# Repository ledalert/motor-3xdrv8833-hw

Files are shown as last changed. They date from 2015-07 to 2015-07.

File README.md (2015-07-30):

# motor-3xdrv8833-hw
Small stepper/dc motor driver board with 3 drv8833

This is still early prototype development. Will add more information once this prototype have been tested.

### Update 2015-07-30
#### Prototype boards have arrived
Silk width was a bit too thin and testing of the boards will be done in the near future.
<a href="http://imgur.com/2IHrIkU">source: imgur.com</a>

### Update 2015-07-20
####Prototype boards have been ordered

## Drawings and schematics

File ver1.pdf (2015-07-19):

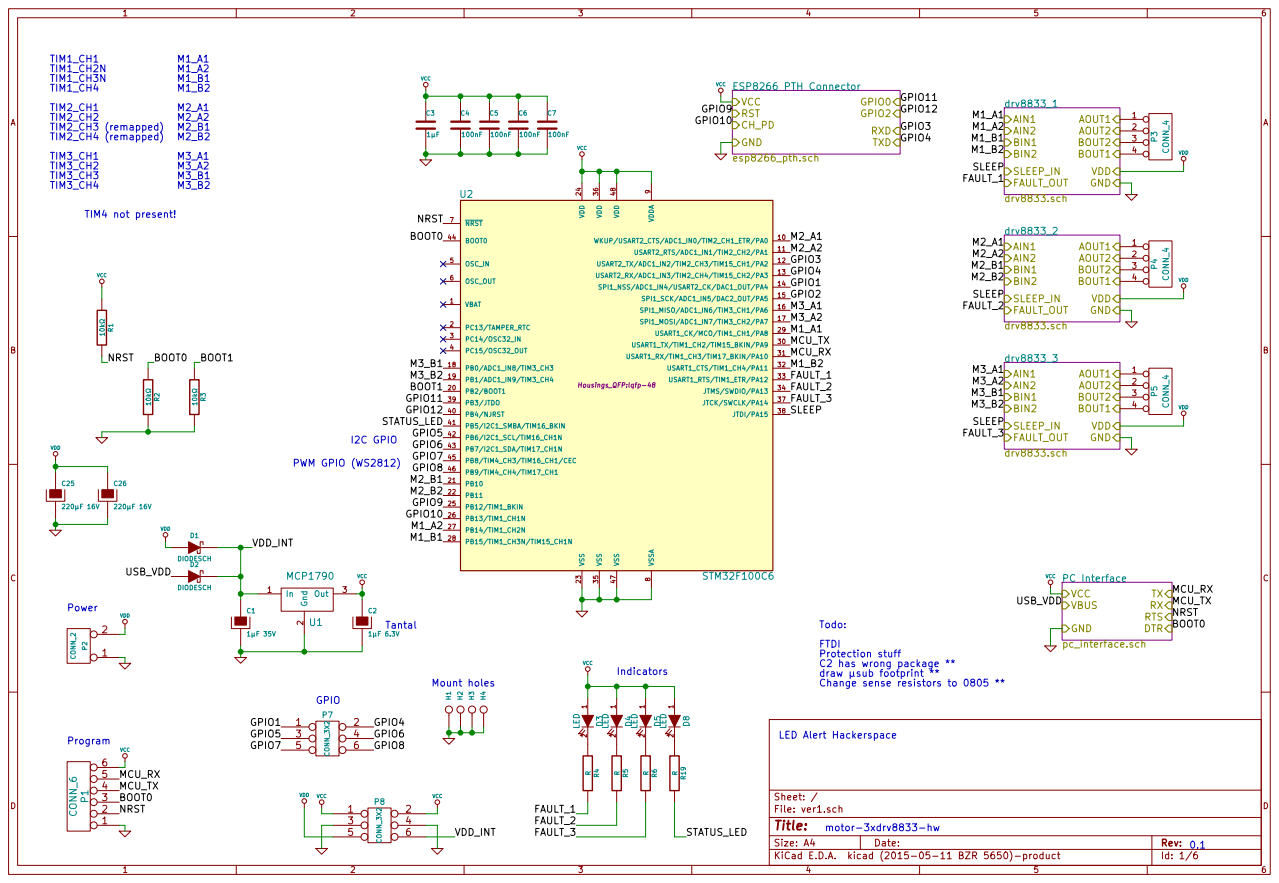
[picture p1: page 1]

9 WKUP/USART2_CTS/ADC1_IN0/TIM2_CH1_ETR/PA0 10 PB2/BOOT1 20 USART1_TX/TIM1_CH2/TIM15_BKIN/PA9 30 PB4/NJRST 40 USART2_RTS/ADC1_IN1/TIM2_CH2/PA1 11 PB10 21 USART1_RX/TIM1_CH3/TIM17_BKIN/PA10 31 PB5/I2C1_SMBA/TIM16_BKIN 41 USART2_TX/ADC1_IN2/TIM2_CH3/TIM15_CH1/PA2 12 PB11 22 USART1_CTS/TIM1_CH4/PA11 32 PB6/I2C1_SCL/TIM16_CH1N 42 USART2_RX/ADC1_IN3/TIM2_CH4/TIM15_CH2/PA3 13 VSS 23 USART1_RTS/TIM1_ETR/PA12 33 PB7/I2C1_SDA/TIM17_CH1N 43 SPI1_NSS/ADC1_IN4/USART2_CK/DAC1_OUT/PA4 14 VDD 24

draw µsub footprint **
Change sense resistors to 0805 ** motor-3xdrv8833-hw

Id: 1/6 Title: File: ver1.sch Sheet: /

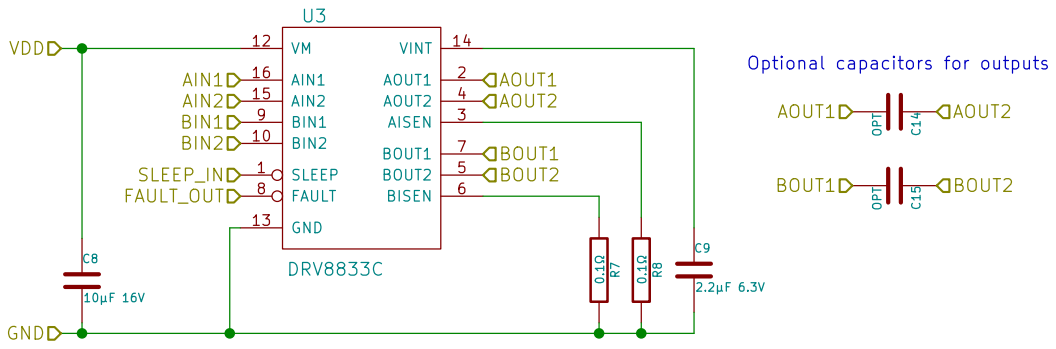
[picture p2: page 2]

Optional capacitors for outputs

Id: 2/6 Title: File: drv8833.sch Sheet: /drv8833_1/

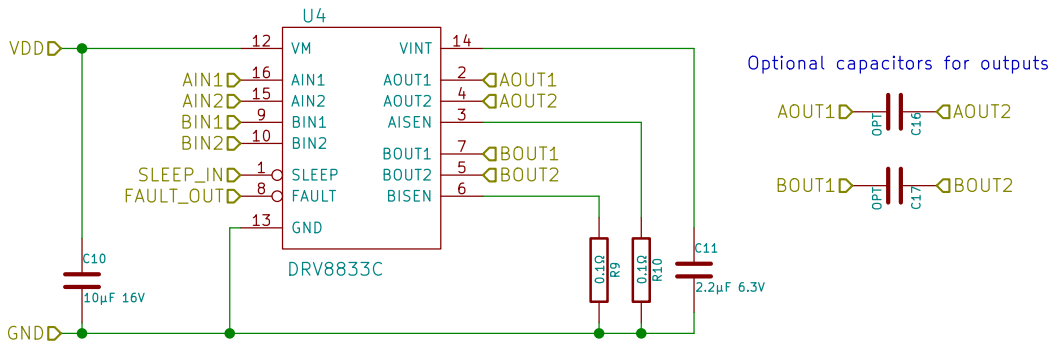
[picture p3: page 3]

Optional capacitors for outputs

Id: 3/6 Title: File: drv8833.sch Sheet: /drv8833_2/

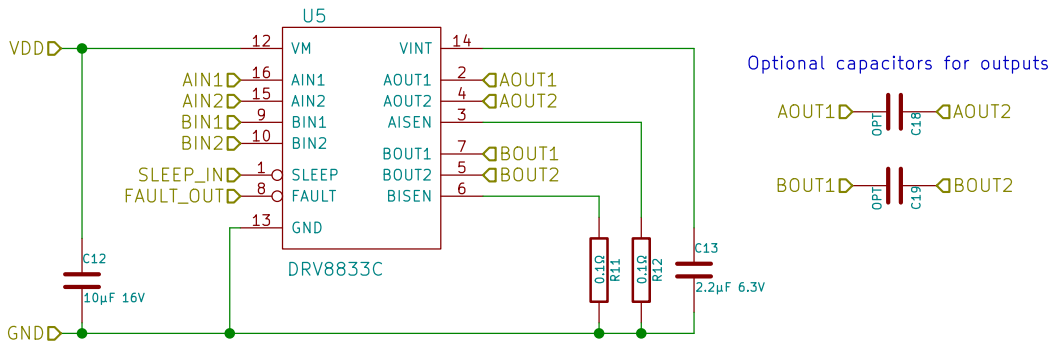
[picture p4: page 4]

Optional capacitors for outputs

Id: 4/6 Title: File: drv8833.sch Sheet: /drv8833_3/

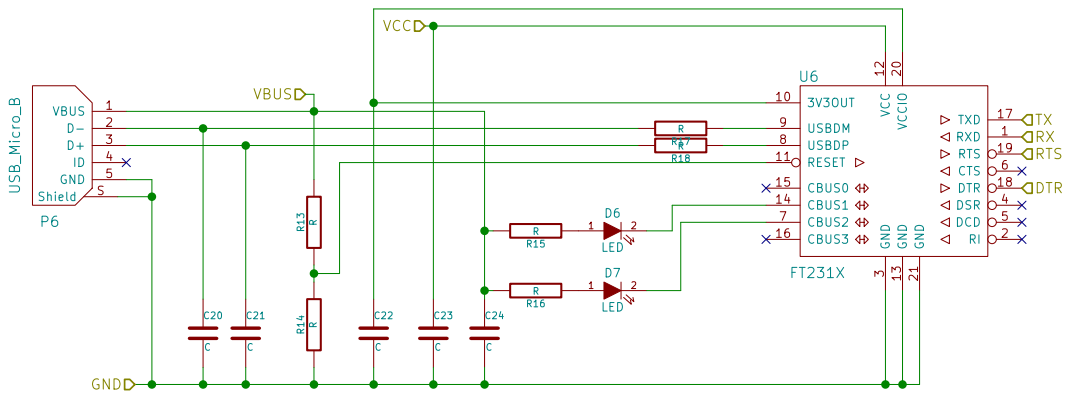
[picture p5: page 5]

3 DSR 4 DCD 5 CTS 6 CBUS2 7 USBDP 8 USBDM 9

File: pc_interface.sch Sheet: /PC Interface/
Id: 5/6 Title:

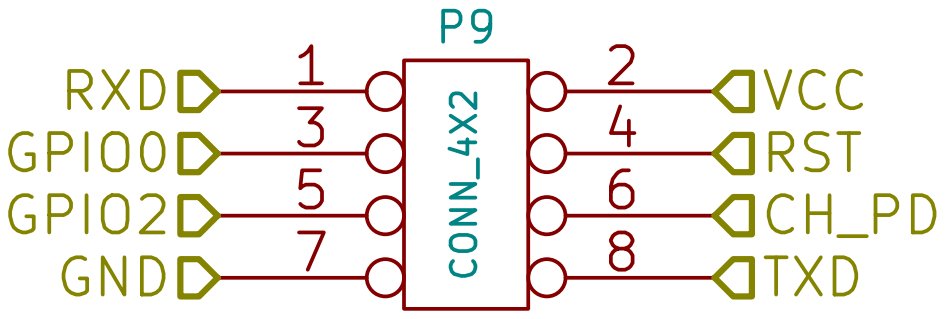
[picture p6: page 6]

File: esp8266_pth.sch Sheet: /ESP8266 PTH Connector/
Id: 6/6 Title:

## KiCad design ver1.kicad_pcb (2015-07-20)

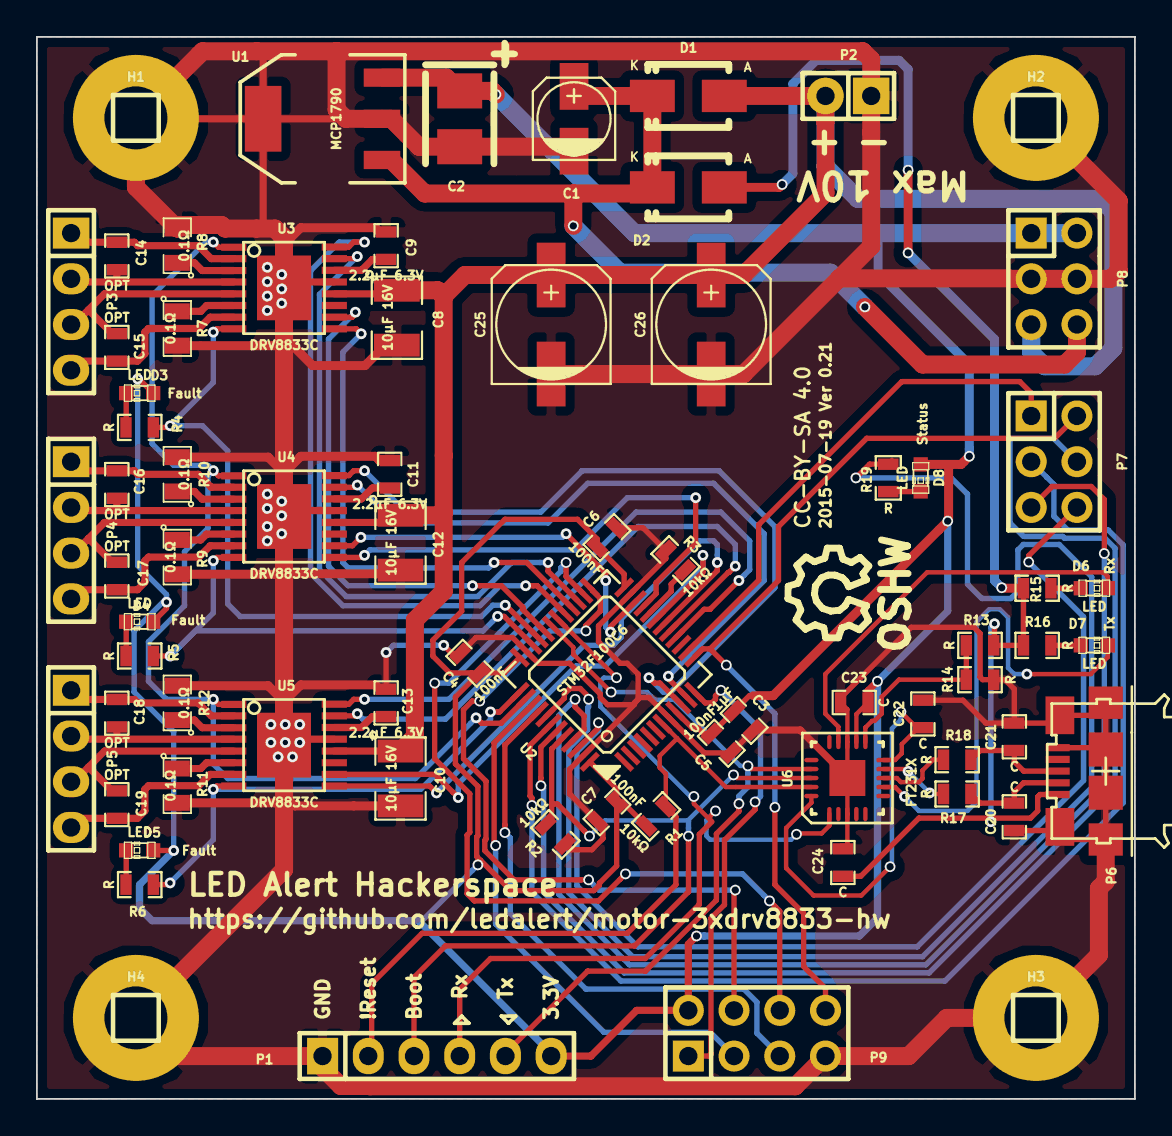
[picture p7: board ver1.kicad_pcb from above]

Board: 2 copper layers, 61.0 x 59.0 mm, 73 parts (0 on the bottom side), 73 nets.

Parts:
C1: 1µF 35V; c_elec_4x5.3
C2: 1µF 6.3V; TantalC_SizeB_EIA-3528_Reflow
C3: 1µF; SMD-0603_c
C4, C5, C6, C7: 100nF; SMD-0603_c
C8, C10, C12: 10µF 16V; SMD-1210
C9, C11, C13: 2.2µF 6.3V; SMD-0603_c
C14, C15, C16, C17, C18, C19: OPT; SMD-0603_c
C20, C21, C22, C23, C24: C; SMD-0603_c
C25, C26: 220µF 16V; c_elec_6.3x7.7
D1, D2: DIODESCH; Diode-SMA_Standard
D3, D4, D5, D6, D7, D8: LED; LED-0603
H1, H2, H3, H4: CONN_1; Pin_Header_Straight_1x01
P1: CONN_6; Pin_Header_Straight_1x06
P2: CONN_2; Pin_Header_Straight_1x02
P3, P4, P5: CONN_4; Pin_Header_Straight_1x04
P6: USB_Micro_B; USB MICRO B
P7, P8: CONN_3X2; Pin_Header_Straight_2x03
P9: CONN_4X2; Pin_Header_Straight_2x04
R1, R2, R3: 10kΩ; SMD-0603_r
R4, R5, R6, R13, R14, R15, R16, R17, R18, R19: R; SMD-0603_r
R7, R8, R9, R10, R11, R12: 0.1Ω; SMD-0805
SYM: Symbol_OSHW-Logo_SilkScreen_07Jul2012; Symbol_OSHW-Logo_SilkScreen
U1: MCP1790; SOT-223
U2: STM32F100C6; lqfp-48
U3, U4, U5: DRV8833C; SSOP-16(EP)
U6: FT231X; QFN_20-1EP

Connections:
/BOOT1: R3.1, U2.20
/ESP8266 PTH Connector/CH_PD: P9.6, U2.26
/ESP8266 PTH Connector/GPIO0: P9.3, U2.39
/ESP8266 PTH Connector/GPIO2: P9.5, U2.40
/ESP8266 PTH Connector/RST: P9.4, U2.25
/ESP8266 PTH Connector/RXD: P9.1, U2.12
/ESP8266 PTH Connector/TXD: P7.2, P9.8, U2.13
/GPIO1: P7.1, U2.14
/GPIO5: P7.3, U2.42
/GPIO6: P7.4, U2.43
/GPIO7: P7.5, U2.45
/GPIO8: P7.6, U2.46
/PC Interface/DTR: P1.3, R2.1, U2.44, U6.18
/PC Interface/RTS: P1.2, R1.2, U2.7, U6.19
/PC Interface/RX: P1.4, U2.30, U6.1
/PC Interface/TX: P1.5, U2.31, U6.17
/PC Interface/VBUS: C24.1, D2.1, P6.1, R13.2, R15.2, R16.2
/STATUS_LED: R19.2, U2.41
/VDD_INT: C1.1, D1.2, D2.2, P8.6, U1.1
/drv8833_1/AIN1: U2.29, U3.16
/drv8833_1/AIN2: U2.27, U3.15
/drv8833_1/AOUT1: C14.2, P3.1, U3.2
/drv8833_1/AOUT2: C14.1, P3.2, U3.4
/drv8833_1/BIN1: U2.28, U3.9
/drv8833_1/BIN2: U2.32, U3.10
/drv8833_1/BOUT1: C15.2, P3.4, U3.7
/drv8833_1/BOUT2: C15.1, P3.3, U3.5
/drv8833_1/FAULT_OUT: R4.2, U2.33, U3.8
/drv8833_1/SLEEP_IN: U2.38, U3.1, U4.1, U5.1
/drv8833_2/AIN1: U2.10, U4.16
/drv8833_2/AIN2: U2.11, U4.15
/drv8833_2/AOUT1: C16.2, P4.1, U4.2
/drv8833_2/AOUT2: C16.1, P4.2, U4.4
/drv8833_2/BIN1: U2.21, U4.9
/drv8833_2/BIN2: U2.22, U4.10
/drv8833_2/BOUT1: C17.2, P4.4, U4.7
/drv8833_2/BOUT2: C17.1, P4.3, U4.5
/drv8833_2/FAULT_OUT: R5.2, U2.34, U4.8
/drv8833_3/AIN1: U2.16, U5.16
/drv8833_3/AIN2: U2.17, U5.15
/drv8833_3/AOUT1: C18.2, P5.1, U5.2
/drv8833_3/AOUT2: C18.1, P5.2, U5.4
/drv8833_3/BIN1: U2.18, U5.9
/drv8833_3/BIN2: U2.19, U5.10
/drv8833_3/BOUT1: C19.2, P5.4, U5.7
/drv8833_3/BOUT2: C19.1, P5.3, U5.5
/drv8833_3/FAULT_OUT: R6.2, U2.37, U5.8
GND: C1.2, C2.2, C3.2, C4.2, C5.2, C6.2, C7.2, C8.2, C9.2, C10.2, C11.2, C12.2, C13.2, C20.2, C21.2, C22.2, C23.2, C24.2, C25.2, C26.2, H1.1, H2.1, H3.1, H4.1, P1.1, P2.1, P6.5, P6.S, P8.3, P8.4, P9.7, R2.2, R3.2, R7.2, R8.2, R9.2, R10.2, R11.2, R12.2, R14.1, U1.2, U1.4, U2.8, U2.23, U2.35, U2.47, U3.13, U3.17, U4.13, U4.17, U5.13, U5.17, U6.3, U6.13, U6.21
unnamed: C9.1, U3.14
unnamed: C11.1, U4.14
unnamed: C13.1, U5.14
unnamed: C20.1, P6.2, R17.2
unnamed: C21.1, P6.3, R18.2
unnamed: C22.1, U6.10, U6.20
unnamed: D3.2, R4.1
unnamed: D4.2, R5.1
unnamed: D5.2, R6.1
unnamed: D6.1, R15.1
unnamed: D6.2, U6.14
unnamed: D7.1, R16.1
unnamed: D7.2, U6.7
unnamed: D8.2, R19.1
unnamed: R7.1, U3.6
unnamed: R8.1, U3.3
unnamed: R9.1, U4.6
unnamed: R10.1, U4.3
unnamed: R11.1, U5.6
unnamed: R12.1, U5.3
unnamed: R13.1, R14.2, U6.11
unnamed: R17.1, U6.9
unnamed: R18.1, U6.8
VCC: C2.1, C3.1, C4.1, C5.1, C6.1, C7.1, C23.1, D3.1, D4.1, D5.1, D8.1, P1.6, P8.1, P8.2, P9.2, R1.1, U1.3, U2.9, U2.24, U2.36, U2.48, U6.12
VDD: C8.1, C10.1, C12.1, C25.1, C26.1, D1.1, P2.2, P8.5, U3.12, U4.12, U5.12

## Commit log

2015-07-11 Done some routing, added fault indicators
    [drv8833.sch, ver1.kicad_pcb, ver1.sch]
2015-07-11 Added footprints, checking in before redoing routing
    [drv8833.sch, pc_interface.sch, ver1.kicad_pcb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]
2015-07-11 Tried a new layout for motor driver output
    [drv8833.sch, pc_interface.sch, ver1.kicad_pcb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]
2015-07-11 Rerouted motor output
    [ver1.kicad_pcb]
2015-07-19 Added PC interface and did some routing
    [drv8833.sch, esp8266_pth.sch, pc_interface.sch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]
2015-07-19 Final routing complete
    [ver1-B_Cu.gbl, ver1-B_Mask.gbs, ver1-B_SilkS.gbo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]
2015-07-19 Updated schematics PDF
2015-07-20 Final changes for v0.21
    [ver1-B_Cu.gbl, ver1-B_Mask.gbs, ver1-B_SilkS.gbo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]

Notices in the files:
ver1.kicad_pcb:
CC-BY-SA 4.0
